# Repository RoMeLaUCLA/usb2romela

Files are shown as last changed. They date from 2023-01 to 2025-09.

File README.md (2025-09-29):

# USB2RoMeLa RS-485 USB Adapter

USB2RoMeLa Boosted is a low latency USB to RS-485 adapter. FT232H is used for USB to serial conversion. STM32 intercepts data packets and signals FT232H whenever a complete data packet is received, lowering roundtrip communication latency.
Packet acceleration is designed around Dynamixel communication protocols. 

 ## System Diagram

 

# Usage

## Baudrate setting

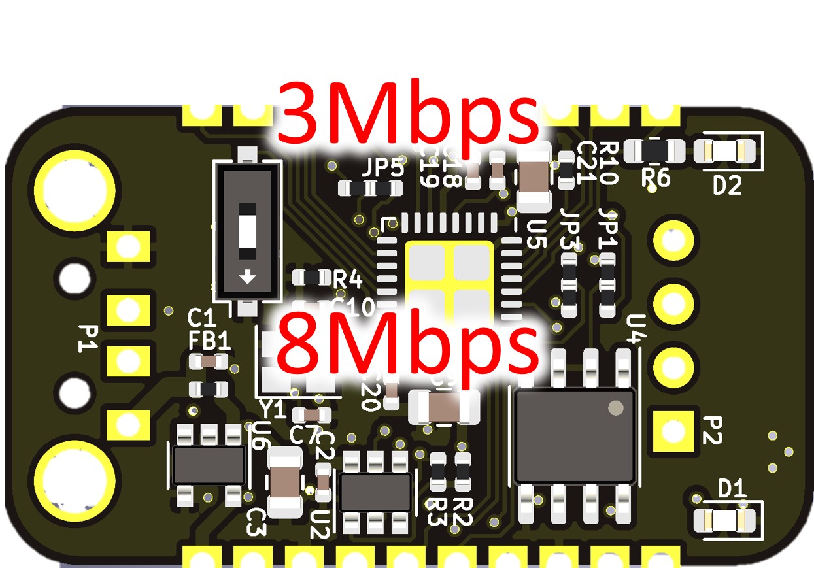
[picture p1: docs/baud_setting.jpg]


## Terminal resistor setting

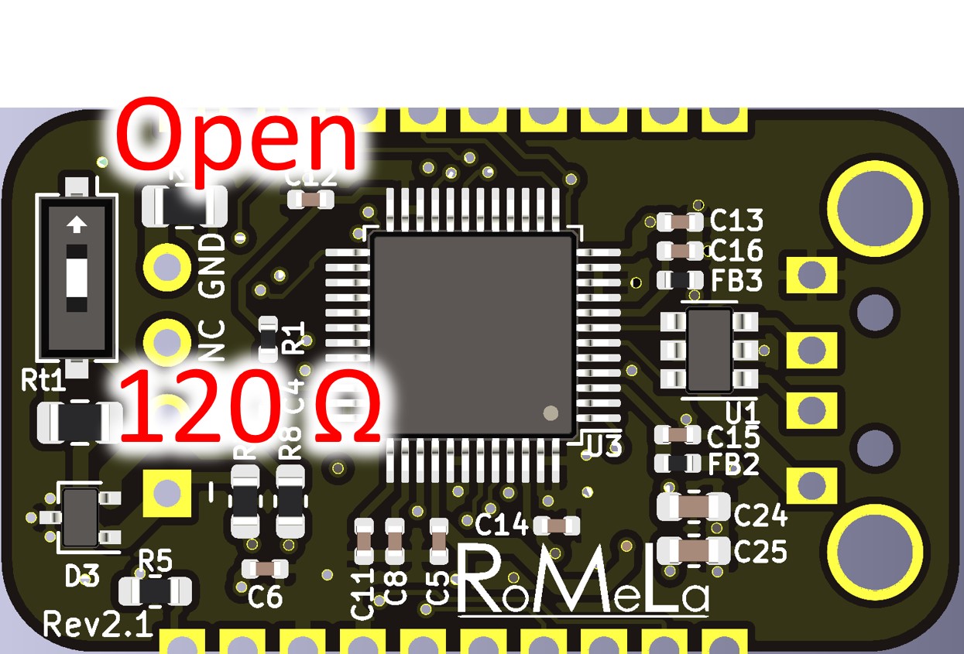
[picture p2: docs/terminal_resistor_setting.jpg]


## Startup code
 - Flash 2 times: 8Mbps
 - Flash 3 times: 3Mbps
## Error code 
 - Flash 1 time: Packet Timeout
 - Flash 2 times: Checksum Error
 - Flash 3 times: UART Error

# PCB reference

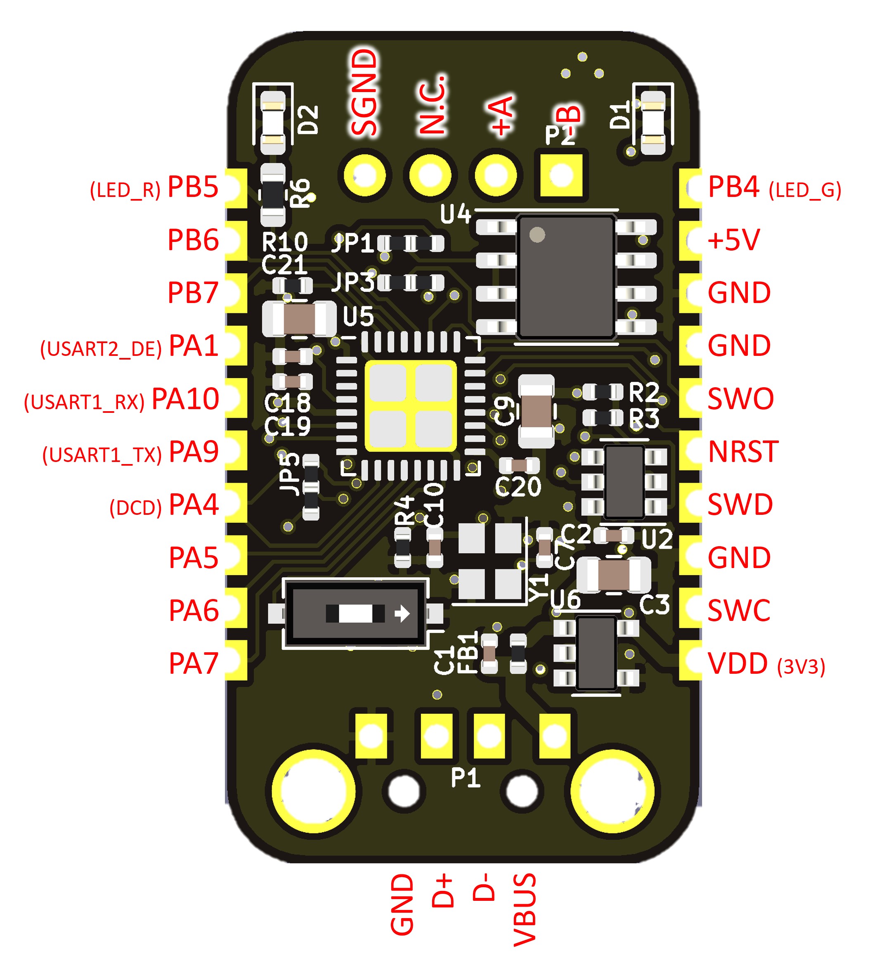
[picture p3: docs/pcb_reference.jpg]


[Link to schematics](/pcb/USB2RoMeLa_Boosted_rev2_1.pdf)

# Latency test

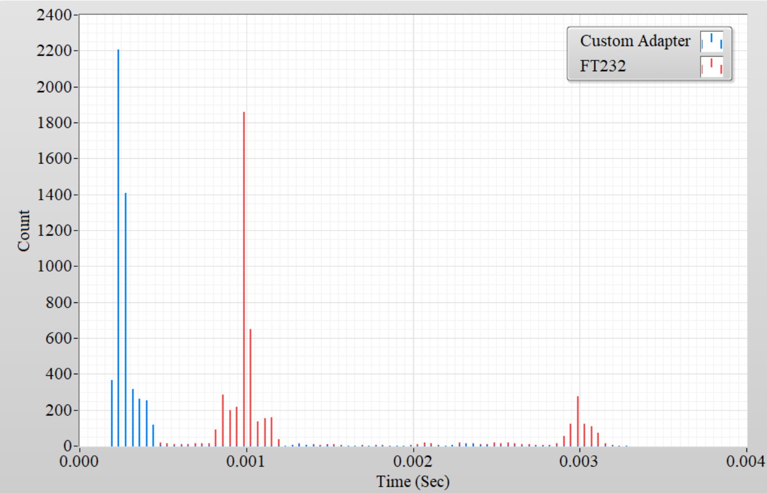
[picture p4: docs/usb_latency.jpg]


# Folder structure

cad: 3D CAD files and render.

firmware: STM32 firmware with STM32CubeIDE project. \
firmware\Bin: binary file of compiled firmware.

pcb: PCB design files(KiCAD) and schematics. \
pcb\BOM: Bill of Materials. \
pcb\Gerber: PCB mfg files.

tools\ftdi-template: template to use when programing FT232H using FT_Prog.

tools\programming-interface-pcb: PCB design files for interface board with castellation.

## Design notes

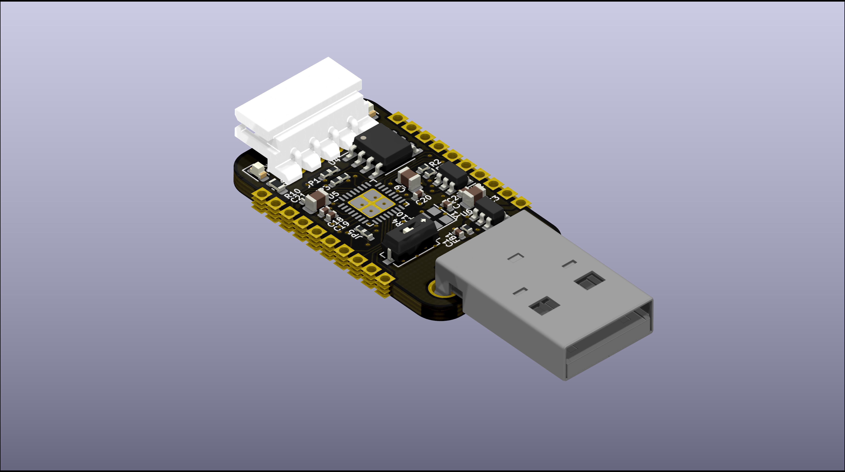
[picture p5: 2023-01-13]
cad/USB2RoMeLa_Boosted_render_1.jpg

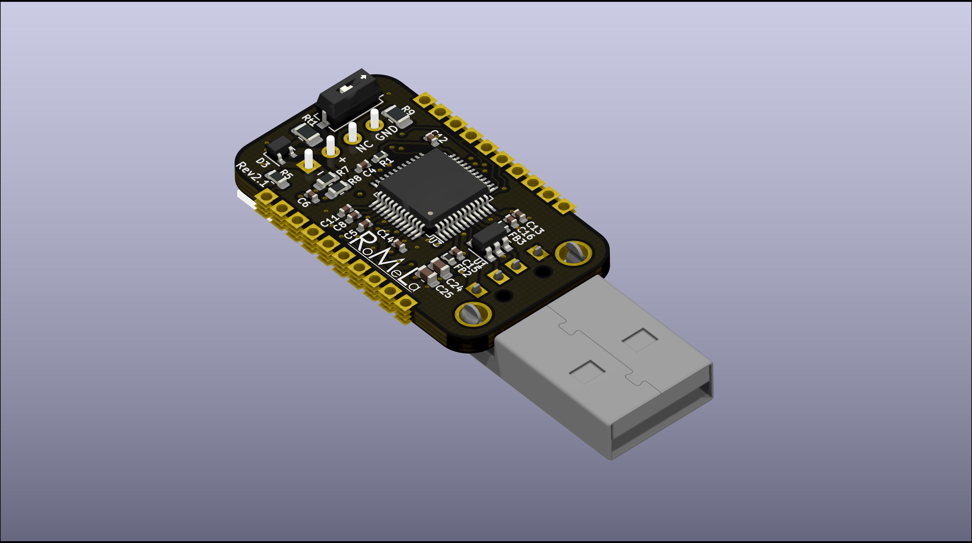
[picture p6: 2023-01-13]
cad/USB2RoMeLa_Boosted_render_2.jpg

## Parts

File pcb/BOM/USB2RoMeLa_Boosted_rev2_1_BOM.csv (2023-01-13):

Manufacturer | Manufacturer Part Number | Designator | Qty | Description | Case | SMD ,BGA,LLC(QFN),ORTH | Top/Bottom | points | Total points | polarity | Notes | Comments
Samsung Electro-Mechanics | CL05B103KB5NNNC | C1, C4 | 2 | 10000pF ±10% 50V Ceramic Capacitor X7R 0402 | 0402 | SMD | Top & Bottom | 2 | 4 |  | Alternative parts accepted upon approval
Samsung Electro-Mechanics | CL05B104KO5NFNC | C2, C5, C6, C8, C11-C16, C18-C20 | 13 | 0.1µF ±10% 16V Ceramic Capacitor X7R 0402 | 0402 | SMD | Top & Bottom | 2 | 26 |  | Alternative parts accepted upon approval
Samsung Electro-Mechanics | CL21B106KPQNFNE | C3, C9, C21 | 3 | 10µF ±10% 10V Ceramic Capacitor X7R 0805 | 0805 | SMD | Top | 2 | 6 |  | Alternative parts accepted upon approval
Samsung Electro-Mechanics | CL05C100DB5NNNC | C7, C10 | 2 | 10pF ±0.5pF 50V Ceramic Capacitor C0G, NP0 0402 | 0402 | SMD | Top | 2 | 4 |  | Alternative parts accepted upon approval
Samsung Electro-Mechanics | CL10B105KP8NFNC | C24, C25 | 2 | 1µF ±10% 10V Ceramic Capacitor X7R 0603 | 0603 | SMD | Bottom | 2 | 4 |  | Alternative parts accepted upon approval
Rohm Semiconductor | SML-D13M8WT86 | D1 | 1 | Green 572nm LED Indication - Discrete 2.2V 0603 | 0603 | SMD | Top | 2 | 2 | Yes | Alternative parts accepted upon approval
Rohm Semiconductor | SML-D12U1WT86 | D2 | 1 | Red 620nm LED Indication - Discrete 2.2V 0603 | 0603 | SMD | Top | 2 | 2 | Yes | Alternative parts accepted upon approval
STMicroelectronics | ESDCAN02-2BWY | D3 | 1 | 44V Clamp 3A (8/20µs) Ipp Tvs Diode Surface Mount SOT-323-3 | SOT-323 | SMD | Bottom | 3 | 3
Murata Electronics | BLM15PX601SN1D | FB1-FB3 | 3 | 600 Ohms Ferrite Bead 0402 230mOhm | 0402 | SMD | Top & Bottom | 2 | 6 |  | Alternative parts accepted upon approval
Bourns Inc. | CR0402-J/-000GLF | JP1, JP3, JP5 | 3 | 0 Ohms Jumper 0402 | 0402 | SMD | Top | 2 | 6 |  | Alternative parts accepted upon approval
 |  | JP2, JP4, JP6 | 3 | D.N.P.
Molex | 0480370001 | P1 | 1 | USB - A USB 2.0 Plug Connector 4 Position Through Hole, Right Angle | USB Header | TH | Top | 6 | 6
Molex | 0022057045 | P2 | 1 | Connector Header Through Hole, Right Angle 4 position 0.098" (2.50mm) | Header 4pin | TH | Top | 4 | 4
Bourns Inc. | CR0402-JW-103GLF | R1, R2, R10 | 3 | 10 kOhms ±5% 0.063W, 1/16W Chip Resistor 0402 | 0402 | SMD | Top & Bottom | 2 | 6 |  | Alternative parts accepted upon approval
Bourns Inc. | CR0402-JW-202GLF | R3 | 1 | 2 kOhms ±5% 0.063W, 1/16W Chip Resistor 0402 | 0402 | SMD | Top | 2 | 2 |  | Alternative parts accepted upon approval
Bourns Inc. | CR0402-FX-1202GLF | R4 | 1 | 12 kOhms ±1% 0.063W, 1/16W Chip Resistor 0402 | 0402 | SMD | Top | 2 | 2 |  | Alternative parts accepted upon approval
Bourns Inc. | CR0603-JW-181ELF | R5, R6 | 2 | 180 Ohms ±5% 0.1W, 1/10W Chip Resistor 0603 | 0603 | SMD | Top & Bottom | 2 | 4 |  | Alternative parts accepted upon approval
Rohm Semiconductor | ESR03EZPF10R0 | R7, R8 | 2 | 10 Ohms ±1% 0.25W 0603 Pulse Withstanding | 0603 | SMD | Bottom | 2 | 4
Rohm Semiconductor | ESR10EZPF1200 | R9, Rt1 | 2 | 120 Ohms ±1% 0.4W 0805 Pulse Withstanding | 0805 | SMD | Bottom | 2 | 4
Nidec Copal Electronics | CHS-01TA | SW1, SW2 | 2 | Dip Switch SPST 1 Position Surface Mount Slide (Standard) Actuator 100mA 6VDC | dip switch | SMD | Top & Bottom | 2 | 4 | Yes
STMicroelectronics | USBLC6-2SC6 | U1 | 1 | 17V Clamp 5A (8/20µs) Ipp Tvs Diode Surface Mount SOT-23-6 | SOT-23-6 | SMD | Bottom | 6 | 6 | Yes
Microchip Technology | 93LC56BT-I/OT | U2 | 1 | EEPROM Memory IC 2Kb (128 x 16) SPI 2MHz SOT-23-6 | SOT-23-6 | SMD | Top | 6 | 6 | Yes
FTDI, Future Technology Devices International Ltd | FT232HL-REEL | U3 | 1 | USB Bridge, USB to UART,FIFO USB 2.0 UART, FIFO Interface 48-LQFP (7x7) | 48-LQFP (7x7) | SMD | Bottom | 48 | 48 | Yes
Maxim Integrated | MAX14775EASA+ | U4 | 1 | 1/1 Transceiver Half RS422, RS485 8-SOIC | 8-SOIC | SMD | Top | 8 | 8 | Yes
STMicroelectronics | STM32L432KBU6 | U5 | 1 | ARM® Cortex®-M4 STM32L4 Microcontroller IC 32-Bit 80MHz 128KB (128K x 8) FLASH 32-UFQFPN (5x5) | 32-UFQFPN (5x5) | QFN | Top | 33 | 33 | Yes
Texas Instruments | TLV70233DBVR | U6 | 1 | Linear Voltage Regulator 3.3V 300mA SOT-23-5 | SOT-23-5 | SMD | Top | 5 | 5
Abracon LLC | ABM10-166-12.000MHZ-T3 | Y1 | 1 | 12MHz ±10ppm Crystal 8pF 125 Ohms 4-SMD, No Lead | 4-SMD, 2.50mm x 2.00mm | SMD | Top | 4 | 4 | Yes | Alternative parts accepted upon approval

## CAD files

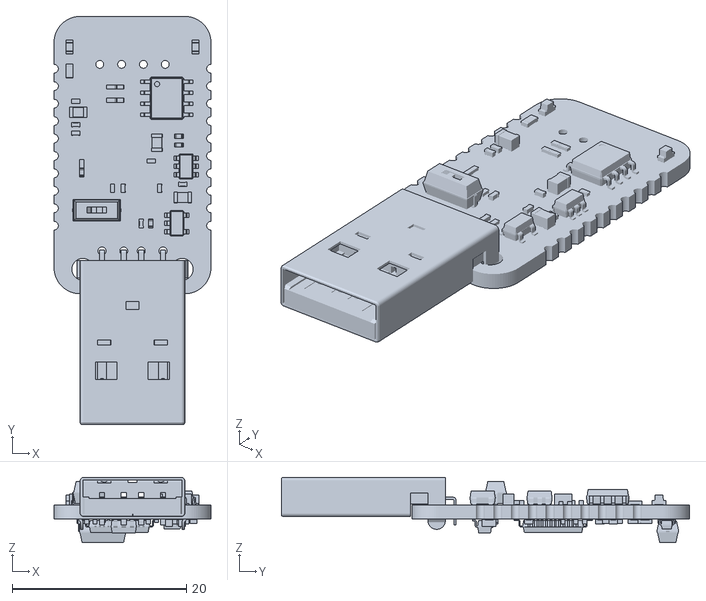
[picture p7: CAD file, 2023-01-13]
cad/USB2RoMeLa_Boosted.STL
18.0 x 46.8 x 7.50

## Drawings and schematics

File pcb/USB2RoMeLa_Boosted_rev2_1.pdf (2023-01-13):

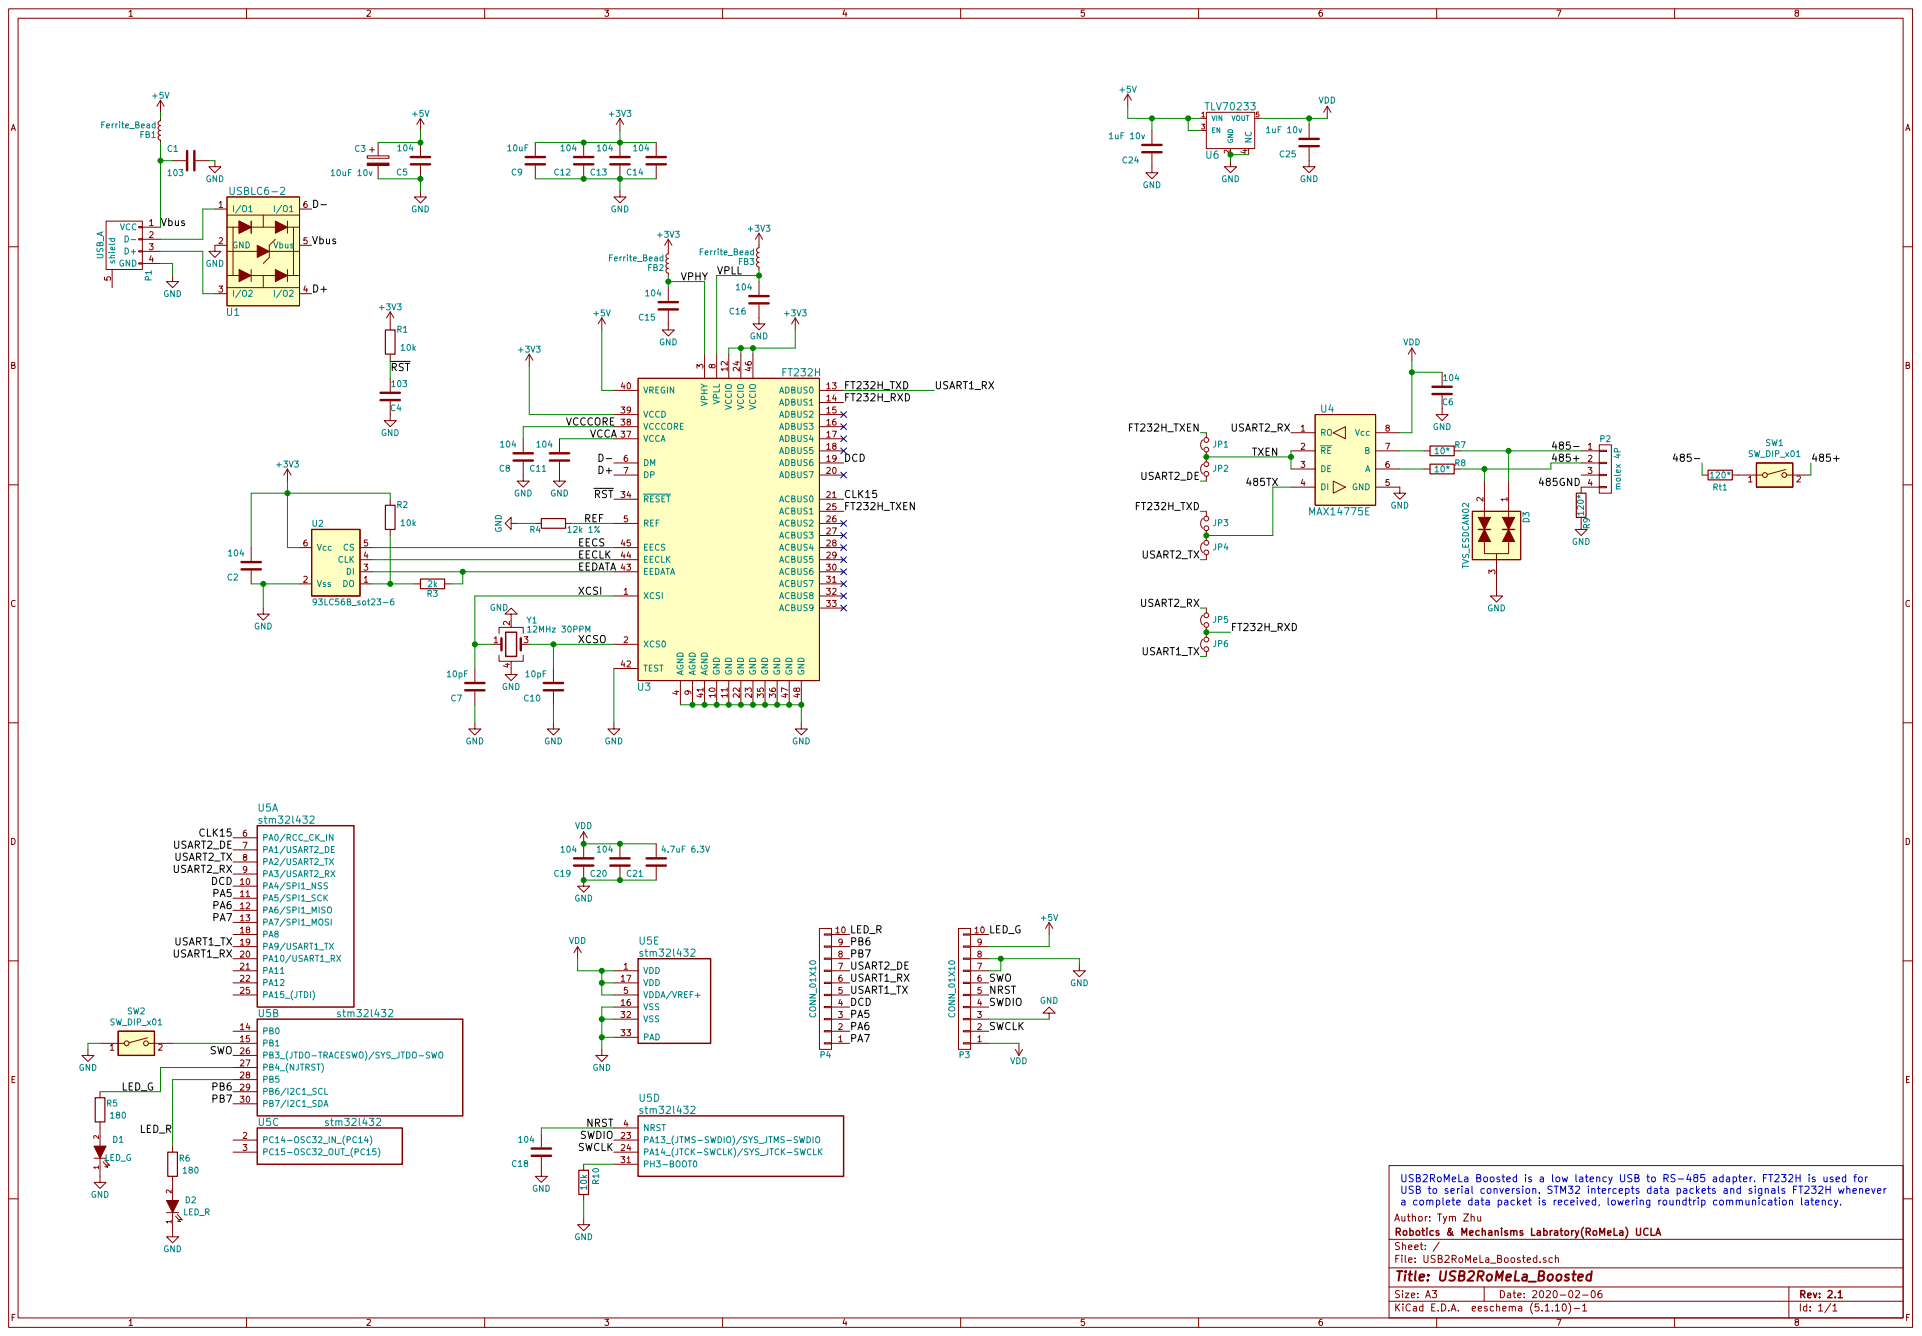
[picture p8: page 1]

4 VREGIN 40 AGND 41 TEST 42 EEDATA 43 EECLK 44 EECS 45 VCCIO 46 GND 47 GND 48 REF 5 DM 6 DP 7 VPLL

3 ACBUS6 30 ACBUS7 31 ACBUS8 32 ACBUS9 33 RESET 34 GND 35 GND 36 VCCA 37 VCCCORE 38 VCCD 39 AGND

Author: Tym Zhu VDD

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

File: USB2RoMeLa_Boosted.sch Sheet: / Robotics & Mechanisms Labratory(RoMeLa) UCLA

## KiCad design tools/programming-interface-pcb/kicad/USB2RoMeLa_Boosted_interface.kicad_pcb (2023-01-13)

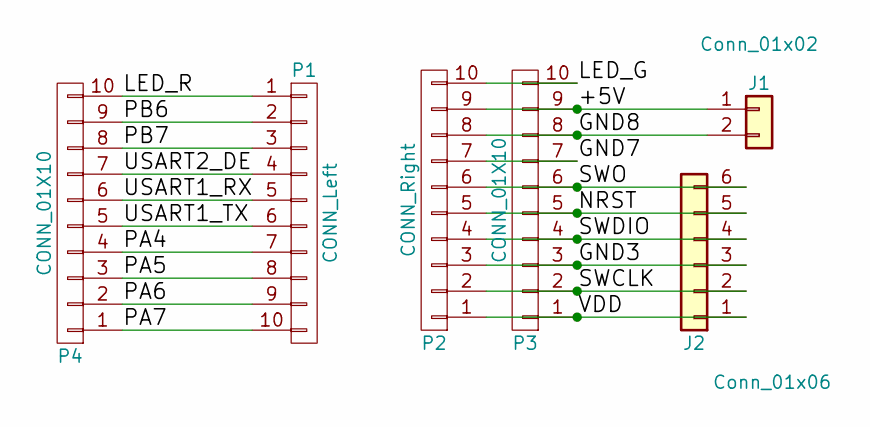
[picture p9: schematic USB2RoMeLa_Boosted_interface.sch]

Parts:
J1: Conn_01x02; Molex_MiniFit-JR-5556-02A_2x01x4.20mm_Straight
J2: Conn_01x06; JST_SH_SM06B-SRSS-TB_06x1.00mm_Angled
P1: CONN_Left; Spring_Contact_10P
P2: CONN_Right; Spring_Contact_10P
P3, P4: CONN_01X10; Socket_Strip_Straight_1x10_Pitch2.54mm

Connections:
/+5V: J1.1, P2.9, P3.9
/GND3: J2.3, P2.3, P3.3
/GND7: P2.7, P3.7
/GND8: J1.2, P2.8, P3.8
/LED_G: P2.10, P3.10
/LED_R: P1.1, P4.10
/NRST: J2.5, P2.5, P3.5
/PA4: P1.7, P4.4
/PA5: P1.8, P4.3
/PA6: P1.9, P4.2
/PA7: P1.10, P4.1
/PB6: P1.2, P4.9
/PB7: P1.3, P4.8
/SWCLK: J2.2, P2.2, P3.2
/SWDIO: J2.4, P2.4, P3.4
/SWO: J2.6, P2.6, P3.6
/USART1_RX: P1.5, P4.6
/USART1_TX: P1.6, P4.5
/USART2_DE: P1.4, P4.7
/VDD: J2.1, P2.1, P3.1

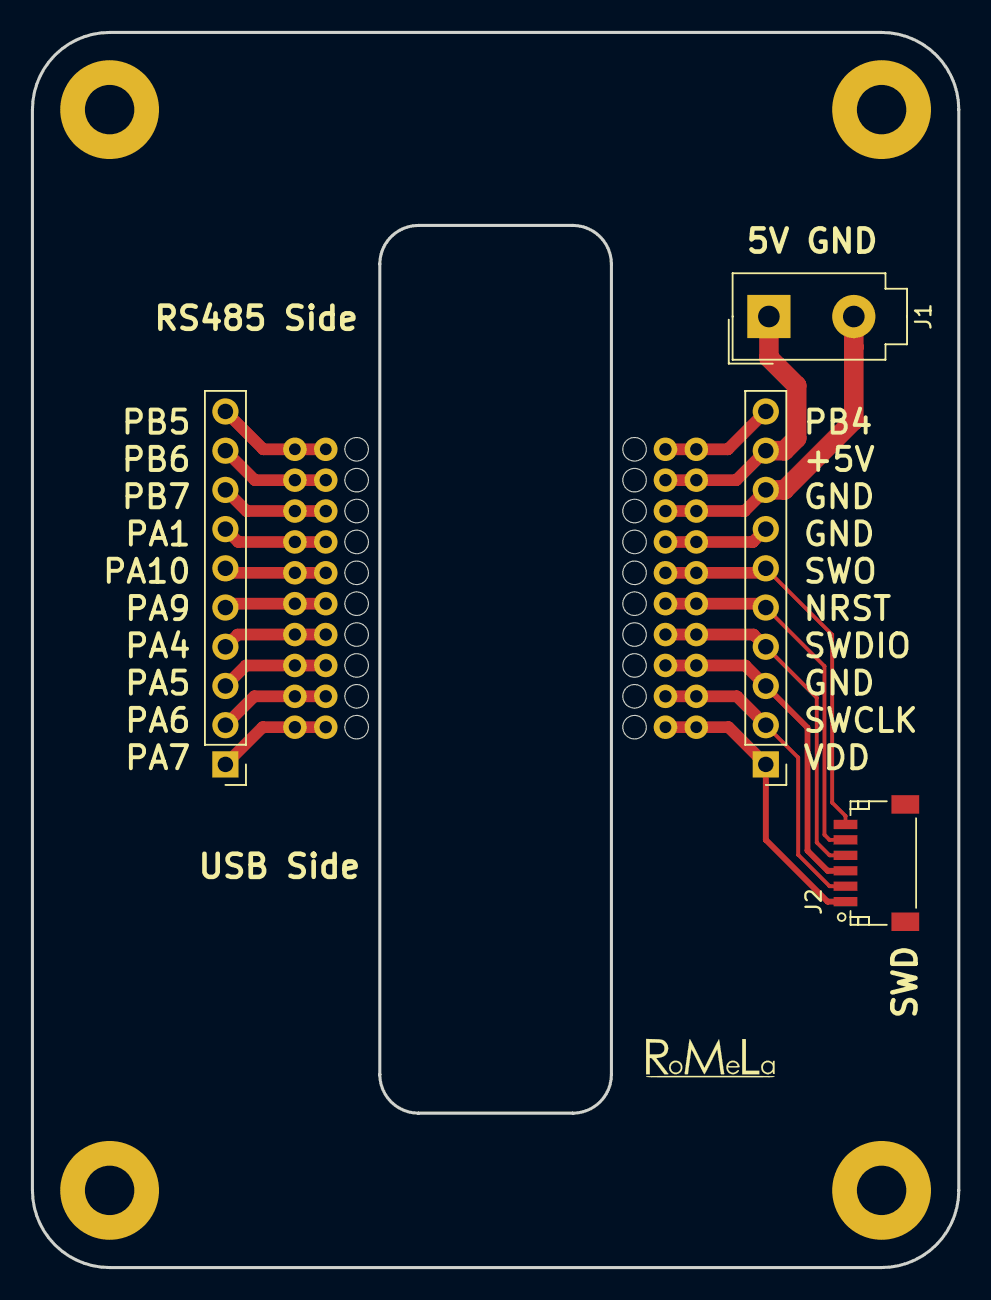
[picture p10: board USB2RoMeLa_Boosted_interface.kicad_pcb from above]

Board: 2 copper layers, 60.0 x 80.0 mm, 6 parts (0 on the bottom side), 20 nets.

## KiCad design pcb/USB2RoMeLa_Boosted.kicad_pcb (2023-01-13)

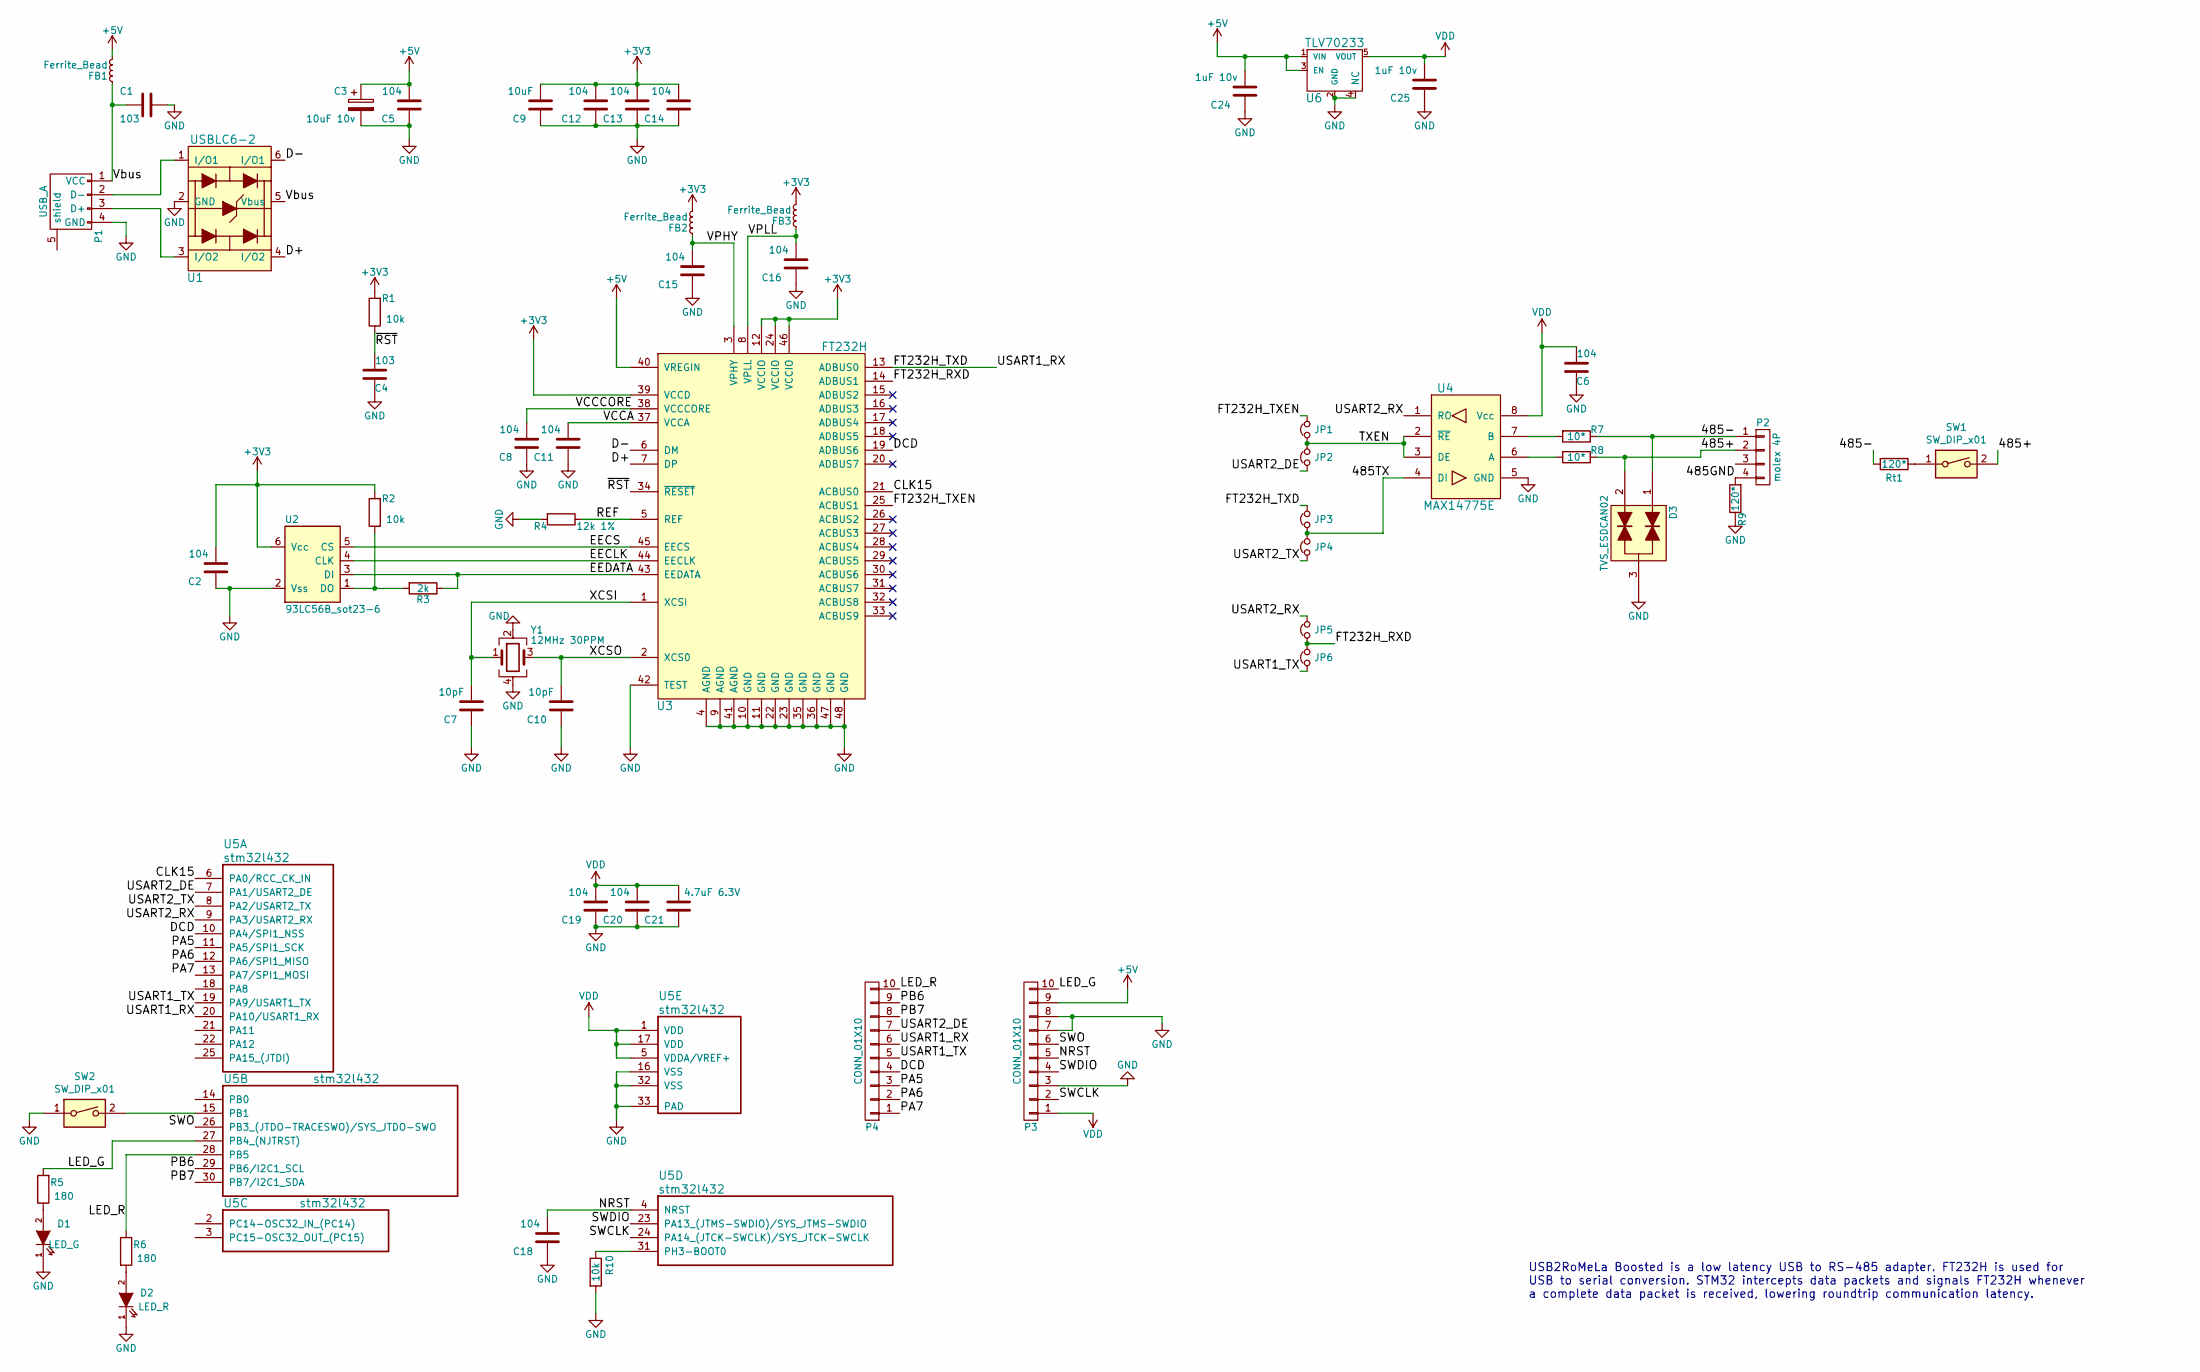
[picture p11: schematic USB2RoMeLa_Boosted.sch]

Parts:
C1, C4: 103; C_0402_1005Metric
C2, C5, C6, C8, C11, C12, C13, C14, C15, C16, C18, C19, C20: 104; C_0402_1005Metric
C3: 10uF 10v; C_0805_2012Metric
C7, C10: 10pF; C_0402_1005Metric
C9: 10uF; C_0805_2012Metric
C21: 4.7uF 6.3V; C_0805_2012Metric
C24, C25: 1uF 10v; C_0603_1608Metric
D1: LED_G; LED_0603_1608Metric
D2: LED_R; LED_0603_1608Metric
D3: TVS_ESDCAN02; SOT-323_SC-70
FB1, FB2, FB3: Ferrite_Bead; R_0402_1005Metric
JP1, JP2, JP3, JP4, JP5, JP6: Jumper_NC_Small; R_0402_1005Metric
P1: USB_A; USB_typeA_TH
P2: molex 4P; Molex_4P
P3, P4: CONN_01X10; castellation_10P_2mm
R1, R2, R10: 10k; R_0402_1005Metric
R3: 2k; R_0402_1005Metric
R4: 12k 1%; R_0402_1005Metric
R5, R6: 180; R_0603_1608Metric
R7, R8: 10*; R_0603_1608Metric
R9: 120*; R_0805_2012Metric
Rt1: 120*; R_0805_2012Metric
SW1, SW2: SW_DIP_x01; SW_DIP_SPSTx01_Slide_Copal_CHS-01A_W5.08mm_P1.27mm_JPin
U1: USBLC6-2; SOT-23-6
U2: 93LC56B_sot23-6; SOT-23-6
U3: FT232H; LQFP-48_7x7mm_P0.5mm
U4: MAX14775E; SOIC-8_3.9x4.9mm_P1.27mm
U5: stm32l432; VQFN-32-1EP_5x5mm_P0.5mm_EP3.5x3.5mm
U6: TLV70233; SOT-23-5
Y1: 12MHz 30PPM; Crystal_SMD_2520-4Pin_2.5x2.0mm

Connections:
+3V3: C2.2, C9.2, C12.2, C13.2, C14.2, FB2.2, FB3.2, R1.2, R2.2, U2.6 (Vcc), U3.12 (VCCIO), U3.24 (VCCIO), U3.39 (VCCD), U3.46 (VCCIO)
+5V: C3.1, C5.2, C24.2, FB1.2, P3.9, U3.40 (VREGIN), U6.1 (VIN), U6.3 (EN)
/485+: D3.2, P2.2, R8.1, SW1.2
/485-: D3.1, P2.1, R7.1, Rt1.2
/485GND: P2.4, R9.2
/485TX: JP3.1, JP4.2, U4.4 (DI)
/CLK15: U3.21 (ACBUS0), U5.6 (PA0/RCC_CK_IN)
/D+: U1.4 (I/O2), U3.7 (DP)
/D-: U1.6 (I/O1), U3.6 (DM)
/DCD: P4.4, U3.19 (ADBUS6), U5.10 (PA4/SPI1_NSS)
/EECLK: U2.4 (CLK), U3.44 (EECLK)
/EECS: U2.5 (CS), U3.45 (EECS)
/EEDATA: R3.1, U2.3 (DI), U3.43 (EEDATA)
/FT232H_RXD: JP5.1, JP6.2, U3.14 (ADBUS1)
/FT232H_TXD: JP3.2, P4.6, U3.13 (ADBUS0), U5.20 (PA10/USART1_RX)
/FT232H_TXEN: JP1.2, U3.25 (ACBUS1)
/LED_G: P3.10, R5.2, U5.27 (PB4_(NJTRST))
/LED_R: P4.10, R6.1, U5.28 (PB5)
/NRST: C18.2, P3.5, U5.4 (NRST)
/PA5: P4.3, U5.11 (PA5/SPI1_SCK)
/PA6: P4.2, U5.12 (PA6/SPI1_MISO)
/PA7: P4.1, U5.13 (PA7/SPI1_MOSI)
/PB6: P4.9, U5.29 (PB6/I2C1_SCL)
/PB7: P4.8, U5.30 (PB7/I2C1_SDA)
/REF: R4.1, U3.5 (REF)
/SWCLK: P3.2, U5.24 (PA14_(JTCK-SWCLK)/SYS_JTCK-SWCLK)
/SWDIO: P3.4, U5.23 (PA13_(JTMS-SWDIO)/SYS_JTMS-SWDIO)
/SWO: P3.6, U5.26 (PB3_(JTDO-TRACESWO)/SYS_JTDO-SWO)
/TXEN: JP1.1, JP2.2, U4.2 (~RE), U4.3 (DE)
/USART1_TX: JP6.1, P4.5, U5.19 (PA9/USART1_TX)
/USART2_DE: JP2.1, P4.7, U5.7 (PA1/USART2_DE)
/USART2_RX: JP5.2, U4.1 (RO), U5.9 (PA3/USART2_RX)
/USART2_TX: JP4.1, U5.8 (PA2/USART2_TX)
/VCCA: C11.2, U3.37 (VCCA)
/VCCCORE: C8.2, U3.38 (VCCCORE)
/VPHY: C15.2, FB2.1, U3.3 (VPHY)
/VPLL: C16.2, FB3.1, U3.8 (VPLL)
/Vbus: C1.2, FB1.1, P1.1 (VCC), U1.5 (Vbus)
/XCSI: C7.2, U3.1 (XCSI), Y1.1
/XCSO: C10.2, U3.2 (XCS0), Y1.3
/~RST: C4.2, R1.1, U3.34 (~RESET)
GND: C1.1, C2.1, C3.2, C4.1, C5.1, C6.1, C7.1, C8.1, C9.1, C10.1, C11.1, C12.1, C13.1, C14.1, C15.1, C16.1, C18.1, C19.1, C20.1, C21.1, C24.1, C25.1, D1.1 (K), D2.1 (K), D3.3, P1.4 (GND), P3.3, P3.7, P3.8, R4.2, R9.1, R10.2, SW2.1, U1.2 (GND), U2.2 (Vss), U3.4 (AGND), U3.9 (AGND), U3.10 (GND), U3.11 (GND), U3.22 (GND), U3.23 (GND), U3.35 (GND), U3.36 (GND), U3.41 (AGND), U3.42 (TEST), U3.47 (GND), U3.48 (GND), U4.5 (GND), U5.16 (VSS), U5.32 (VSS), U5.33 (PAD), U6.2 (GND), U6.4 (NC), Y1.2, Y1.4
unnamed: D1.2 (A), R5.1
unnamed: D2.2 (A), R6.2
unnamed: P1.2 (D-), U1.1 (I/O1)
unnamed: P1.3 (D+), U1.3 (I/O2)
unnamed: R2.1, R3.2, U2.1 (DO)
unnamed: R7.2, U4.7 (B)
unnamed: R8.2, U4.6 (A)
unnamed: R10.1, U5.31 (PH3-BOOT0)
unnamed: Rt1.1, SW1.1
unnamed: SW2.2, U5.15 (PB1)
VDD: C6.2, C19.2, C20.2, C21.2, C25.2, P3.1, U4.8 (Vcc), U5.1 (VDD), U5.5 (VDDA/VREF+), U5.17 (VDD), U6.5 (VOUT)

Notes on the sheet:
USB2RoMeLa Boosted is a low latency USB to RS-485 adapter. FT232H is used for USB to serial conversion. STM32 intercepts data packets and signals FT232H whenever a complete data packet is received, lowering roundtrip communication latency.

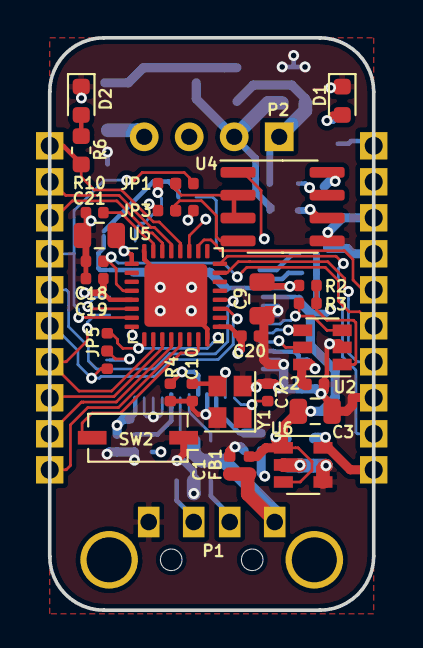
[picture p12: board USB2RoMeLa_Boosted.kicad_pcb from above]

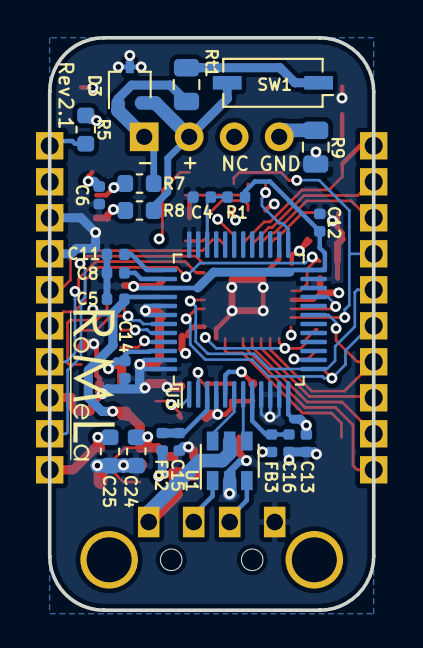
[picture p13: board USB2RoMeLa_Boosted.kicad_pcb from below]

Board: 4 copper layers, 18.0 x 31.8 mm, 58 parts (24 on the bottom side), 53 nets.

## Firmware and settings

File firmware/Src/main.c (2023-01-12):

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
/* Includes ------------------------------------------------------------------*/
#include "main.h"

/* USER CODE BEGIN Includes */
#include "config.h"
/* USER CODE END Includes */

UART_HandleTypeDef huart1;
UART_HandleTypeDef huart2;

/* USER CODE BEGIN PV */



LED_TypeDef LED_R;
LED_TypeDef LED_G;

volatile Packet_TypeDef RX;
volatile Packet_TypeDef TX;

volatile uint32_t Global_Error = 0;


/* USER CODE END PV */

void SystemClock_Config(void);
static void MX_GPIO_Init(void);
static void MX_USART1_UART_Init(void);
static void MX_USART2_UART_Init(void);
/* USER CODE BEGIN PFP */
void LED_Routine();

/* USER CODE END PFP */

/**
  * @brief  The application entry point.
  * @retval int
  */
int main(void)
{
  /* MCU Configuration--------------------------------------------------------*/

  /* Reset of all peripherals, Initializes the Flash interface and the Systick. */
  HAL_Init();

  /* Configure the system clock */
  SystemClock_Config();

  /* Initialize all configured peripherals */
  MX_GPIO_Init();
  MX_USART1_UART_Init();
  MX_USART2_UART_Init();
  /* USER CODE BEGIN 2 */
	
	
	/*Initialize UART*/
	
	HAL_UART_DeInit(&HUART_PC);
	HAL_UART_DeInit(&HUART_MOTOR);
	
	/* Change baudrate based on dip switch position */
	if (BAUD_SW)
	{
		LED_R.Pattern=2;
		HUART_PC.Init.BaudRate = 8000000;
		HUART_MOTOR.Init.BaudRate = 8000000;
	}
	else
	{
		LED_R.Pattern=3;
		HUART_PC.Init.BaudRate = 3000000;
		HUART_MOTOR.Init.BaudRate = 3000000;
	}
	
	LED_R.Cycles=1;
	
	/* UART1 from PC */
	HAL_UART_Init(&HUART_PC);
	/* UART2 from motors */
	HAL_UART_Init(&HUART_MOTOR);
	
	/* Enable the UART Error Interrupt: (Frame error, noise error, overrun error) */
	SET_BIT(USART_PC->CR3, USART_CR3_EIE);
	/* Enable the UART Parity Error interrupt and Data Register Not Empty interrupt */
	SET_BIT(USART_PC->CR1, USART_CR1_PEIE | USART_CR1_RXNEIE);
	
	/* Enable the UART Error Interrupt: (Frame error, noise error, overrun error) */
	SET_BIT(USART_MOTOR->CR3, USART_CR3_EIE);
	/* Enable the UART Parity Error interrupt and Data Register Not Empty interrupt */
	SET_BIT(USART_MOTOR->CR1, USART_CR1_PEIE | USART_CR1_RXNEIE);
	
	
	LED_G_ON();
	
  /* USER CODE END 2 */

  /* Infinite loop */
  /* USER CODE BEGIN WHILE */
	while (1)
	{
    /* USER CODE END WHILE */

    /* USER CODE BEGIN 3 */
		
		/*Watchdog*/
		//HAL_IWDG_Refresh(&hiwdg);
		
	}
	
	
	
  /* USER CODE END 3 */
}

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
/* USER CODE BEGIN 4 */

/**
 * @brief Turn on specific LED
 *
 * @param LED pointer to LED type define
 */
inline static void LED_ON(LED_TypeDef *LED)
{
	if (LED == (&LED_G))
		LED_G_ON();
	else
		LED_R_ON();
}

/**
 * @brief Turn off specific LED
 *
 * @param LED pointer to LED type define
 */
inline static void LED_OFF(LED_TypeDef *LED)
{
	if (LED == (&LED_G))
		LED_G_OFF();
	else
		LED_R_OFF();
}

/**
 * @brief LED routine to handle LED flash patterns.
 *
 * @param LED pointer to LED type define
 */
void LED_Routine(LED_TypeDef *LED)
{

	if (LED->Pattern)
	{
		/* has pattern */

		if (Pattern_State[LED->Pattern - 1][LED->Pattern_Step])
			LED->CT = 1;	//LED_ON(LED);
//		else
//			LED_OFF(LED);

		LED->Pattern_CT++;

		if (LED->Pattern_CT
				> Pattern_Delay[LED->Pattern - 1][LED->Pattern_Step])
		{
			/* Next step */
			LED->Pattern_CT = 0;

			LED->Pattern_Step++;
			if (LED->Pattern_Step >= Pattern_Length[LED->Pattern - 1])
			{
				/*over the length limit*/
				LED->Pattern_Step = 0;
				if (LED->Cycles)
					LED->Cycles--;
				if (LED->Cycles == 0)
				{
					/*done pattern cycles*/
					LED->Pattern = 0;
				}
			}
		}

	}

	if (LED->CT)
	{
		LED_ON(LED);
		LED->CT--;
	}
	else
		LED_OFF(LED);

}

/**
 * @brief routine called at systick, 1kHz
 *
 */
void HAL_SYSTICK_Callback(void)
{

	/* if not idle -> count up */
	if (RX.Packet_Stat != IDLE)
		RX.Idle_CT++;
	else
		RX.Idle_CT = 0;

	if (RX.Idle_CT > RX_NON_IDLE_LIMIT)
	{
		//RX timeout
		Global_Error |= ERR_PACKET_TIMEOUT;
		RX.Packet_Stat = IDLE;
	}

	/* if not idle -> count up */
	if (TX.Packet_Stat != IDLE)
		TX.Idle_CT++;
	else
		TX.Idle_CT = 0;
	if (TX.Idle_CT > TX_NON_IDLE_LIMIT)
	{
		//TX timeout
		Global_Error |= ERR_PACKET_TIMEOUT;
		TX.Packet_Stat = IDLE;
	}

	/* Error handling */
	if (Global_Error & ERR_UART)
	{
		LED_G.Pattern = 3;
		LED_G.Cycles = 5;
		Global_Error &= (~ERR_UART);
	}
	else if (Global_Error & ERR_CHECKSUM)
	{
		LED_G.Pattern = 2;
		LED_G.Cycles = 5;
		Global_Error &= (~ERR_CHECKSUM);
	}
	else if (Global_Error & ERR_PACKET_TIMEOUT)
	{
		LED_G.Pattern = 1;
		LED_G.Cycles = 5;
		Global_Error &= (~ERR_PACKET_TIMEOUT);
	}

	/* Green LED normally always on */
	if (LED_G.Cycles == 0)
		LED_G_FLASH();

	LED_Routine(&LED_R);
	LED_Routine(&LED_G);
}

/**
 * @brief UART Error callback
 *
 * @param huart
 */
void HAL_UART_ErrorCallback(UART_HandleTypeDef *huart)
{

	if (huart == &HUART_MOTOR)
	{
		Global_Error |= ERR_UART;
		//HAL_UART_GetError(huart);

		RX.Packet_Stat = IDLE;
		/* Enable the UART Error Interrupt: (Frame error, noise error, overrun error) */
		SET_BIT(HUART_MOTOR.Instance->CR3, USART_CR3_EIE);
		/* Enable the UART Parity Error interrupt and Data Register Not Empty interrupt */
		SET_BIT(HUART_MOTOR.Instance->CR1, USART_CR1_PEIE | USART_CR1_RXNEIE);
	}
	else if (huart == &HUART_PC)
	{
		Global_Error |= ERR_UART;

		TX.Packet_Stat = IDLE;
		/* Enable the UART Error Interrupt: (Frame error, noise error, overrun error) */
		SET_BIT(HUART_PC.Instance->CR3, USART_CR3_EIE);
		/* Enable the UART Parity Error interrupt and Data Register Not Empty interrupt */
		SET_BIT(HUART_PC.Instance->CR1, USART_CR1_PEIE | USART_CR1_RXNEIE);

	}

}





/* USER CODE END 4 */
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


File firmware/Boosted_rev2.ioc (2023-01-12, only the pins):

Mcu.UserName=STM32L432KCUx
PA0.Signal=RCC_CK_IN
PA10.Signal=USART1_RX
PA2.Signal=USART2_TX
PA3.Signal=USART2_RX
PA4.GPIO_Label=DCD
PA4.Signal=GPIO_Output
PA9.Signal=USART1_TX
PB1.GPIO_Label=SW
PB1.Signal=GPIO_Input
PB5.GPIO_Label=LED_R
PB5.Signal=GPIO_Output

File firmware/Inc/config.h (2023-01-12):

/**
 * @file 	config.h
 * @brief 	All configurations and macros related to the project.
 *
 * @author 	Tym Zhu
 */
#ifndef __CONFIG_H
#define __CONFIG_H

#include "stm32l4xx_hal.h"

/* Macros for GPIOs */
#define LED_R_ON()			LED_R_GPIO_Port->BSRR=(uint32_t)LED_R_Pin //SET
#define LED_R_OFF()			LED_R_GPIO_Port->BRR=(uint32_t)LED_R_Pin //RESET
#define LED_R_TOGGLE()		LED_R_GPIO_Port->ODR ^= LED_R_Pin //Toggle

#define LED_G_ON()			LED_G_GPIO_Port->BSRR=(uint32_t)LED_G_Pin //SET
#define LED_G_OFF()			LED_G_GPIO_Port->BRR=(uint32_t)LED_G_Pin //RESET
#define LED_G_TOGGLE()		LED_G_GPIO_Port->ODR ^= LED_G_Pin //Toggle

#define DCD_ON()			DCD_GPIO_Port->BSRR=((uint32_t)DCD_Pin)<<16U //SET
#define DCD_OFF()			DCD_GPIO_Port->BSRR=DCD_Pin //RESET

#define BAUD_SW				(((SW_GPIO_Port->IDR & SW_Pin) != 0) ? 1:0)

/* Macros for LED */
#define LED_DELAY			2
#define LED_R_FLASH()		LED_R.CT=LED_DELAY
#define LED_G_FLASH()		LED_G.CT=LED_DELAY

/* HUART definition */
#define HUART_PC			huart1
#define USART_PC			USART1
#define HUART_MOTOR			huart2
#define USART_MOTOR			USART2

/* Error definition */
#define ERR_PACKET_TIMEOUT	0x01
#define ERR_CHECKSUM		0x02
#define ERR_UART			0x04

/* communication non-idle time limit */
#define RX_NON_IDLE_LIMIT	20 //ms
#define TX_NON_IDLE_LIMIT	20 //ms


/** Buffer structure */
typedef struct
{
	uint16_t Pt;
	uint16_t Done;
	uint8_t Buffer[256];
} Buffer_TypeDef;

/** Packet status structure */
typedef enum
{
	IDLE = 0,
	HEADER0,
	HEADER1,
	HEADER2,
	RESERVED,
	ID,
	LEN_L,
	LEN_H,
	PAYLOAD,
	ID_10,

} Packet_Stat_TypeDef;

/** Data packet type define */
typedef struct
{
	Packet_Stat_TypeDef Packet_Stat;
	uint16_t Packet_Size;
	uint8_t CheckSum;
	uint8_t Bulk_Read_Num;
	uint8_t Type;
	uint32_t Idle_CT;
	Buffer_TypeDef Buff;

	uint8_t BEAR_Bulk_Header;

} Packet_TypeDef;

/** LED structure */
typedef struct
{
	uint32_t CT;
	uint8_t Pattern;
	uint8_t Pattern_Step;
	uint32_t Pattern_CT;
	uint8_t Cycles;

} LED_TypeDef;

/* LED flash patterns */
static const uint8_t Pattern_Length[] =
{ 3, 5, 7, 9 };
static const uint32_t Pattern_Delay[4][9] =
{
{ 1, 100, 2000 },
{ 1, 100, 500, 100, 2000 },
{ 1, 100, 500, 100, 500, 100, 2000 },
{ 1, 100, 500, 100, 500, 100, 500, 100, 2000 } };
static const uint8_t Pattern_State[4][9] =
{
{ 0, 1, 0 },
{ 0, 1, 0, 1, 0 },
{ 0, 1, 0, 1, 0, 1, 0 },
{ 0, 1, 0, 1, 0, 1, 0, 1, 0 } };

#endif 

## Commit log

2023-01-13 added PCB files.
    [USB2RoMeLa_Boosted.kicad_pcb, USB2RoMeLa_Boosted.sch]
2023-01-13 pcb gerber files
    [USB2RoMeLa_Boosted-B_Cu.gbr, USB2RoMeLa_Boosted-B_Mask.gbr, USB2RoMeLa_Boosted-B_Paste.gbr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]
2023-01-13 added 3D model.
    [USB2RoMeLa_Boosted.STL]
2023-01-13 added interface pcb. re-organized files.
    [USB2RoMeLa_Boosted-B.Cu.gbr, USB2RoMeLa_Boosted-B.Mask.gbr, USB2RoMeLa_Boosted-B.SilkS.gbr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]

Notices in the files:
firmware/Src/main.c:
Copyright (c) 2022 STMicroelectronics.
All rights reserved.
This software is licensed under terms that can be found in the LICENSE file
